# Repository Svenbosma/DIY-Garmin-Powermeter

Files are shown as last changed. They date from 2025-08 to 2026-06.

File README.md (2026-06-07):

# DIY Cycling Power Meter

**What I've made**

A fully working BLE cycling power meter mounted on the left crank of my gravel bike. It broadcasts via Bluetooth using the standard **Cycling Power Profile** so it just shows up as a power meter in Garmin, Wahoo, Zwift, TrainerRoad, or whatever you ride with.

---

## The Story

I am a big nerd and as soon as I got into cycling, I of course wanted more data. The best data for cycling is of course power, so I quickly stumbled down the path of wanting to buy a power meter. Commercial power meters start around €300 and go up fast. I stared at the price tags for a while, then thought: *how hard can it be, it's just a strain gauge readout and some Bluetooth*.

Spoiler: harder than expected. Been working on it (off and on) for a bit less than a year now.

The first version used the **right crank**, which turned out to be a pain. Issues with clearance and wiring routing to the battery which I wanted to fit inside the hollow crank. After some frustration I switched to the **left crank**, which has a larger clearance between rear fork and pedals and makes everything much neater.

### Things I Struggled With

- Getting the HX711 data to be readable
- The Bluetooth Cycling Power Profile spec is... not exactly beginner-friendly documentation
- Getting Garmin to accept and display the zero-offset calibration correctly (there's a whole control-point dance involved)
- **Battery life**, early iterations with 350Ω gauges drew too much current. Switching to **1kΩ Wheatstone bridge sensors** cut standby current dramatically
- Cadence via gyro integration works great but needed careful deadband tuning to avoid phantom revolutions at low speeds
- Making it weatherproof enough for wet rides while still being easy to charge
- Worst of all, testing cadence on my record player. Fine-tuning for weeks because I thought I was off, only to find out my record player was off and the cadence measurement was actually on point. 

The final unit draws **~10mA while riding** and **~0.07mA in standby**. The 300mAh battery lasts a very long time.

---

## The Final Result

| | |
|---|---|
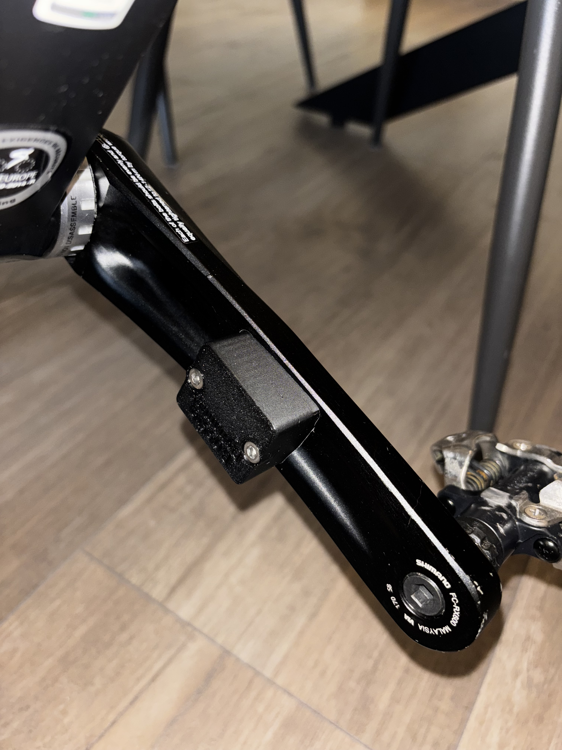
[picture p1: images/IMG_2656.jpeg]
| Mounted on the Shimano left crank |  |
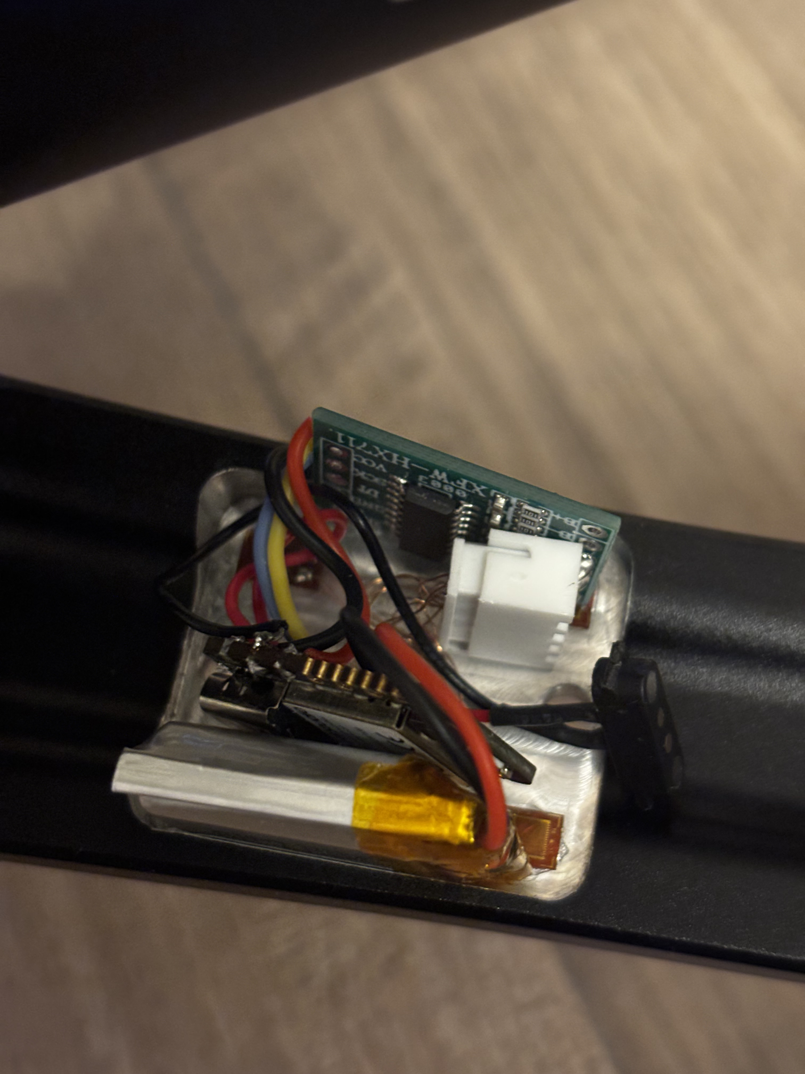
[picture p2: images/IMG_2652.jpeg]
| Electronics on the crank |  |
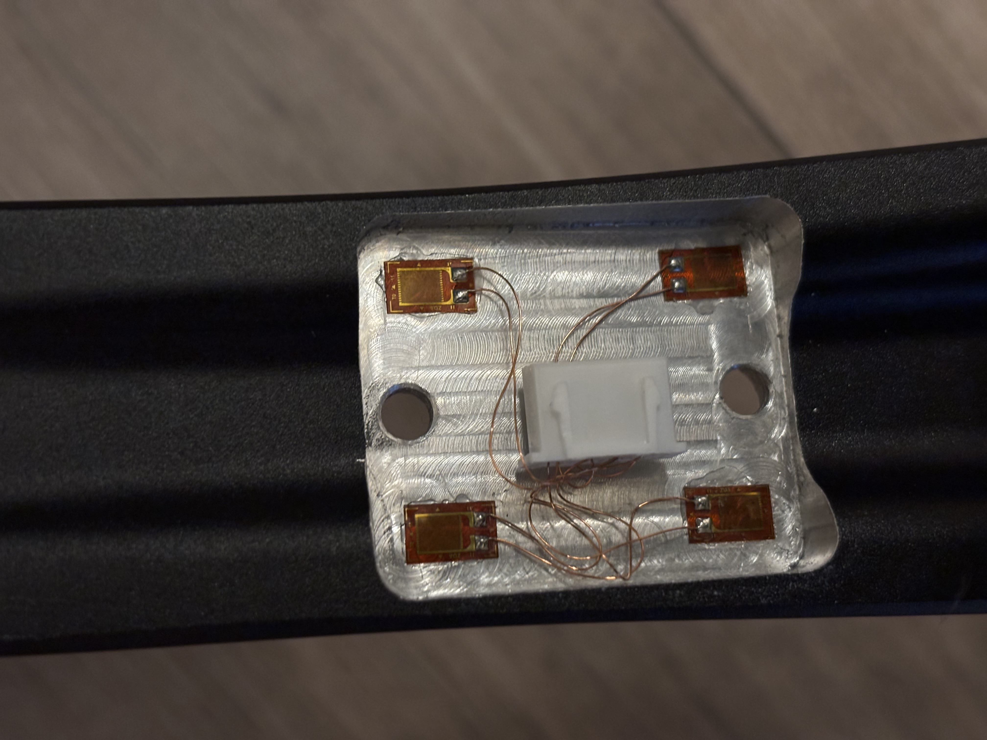
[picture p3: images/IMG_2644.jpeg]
| 4× strain gauges in Wheatstone bridge |  |
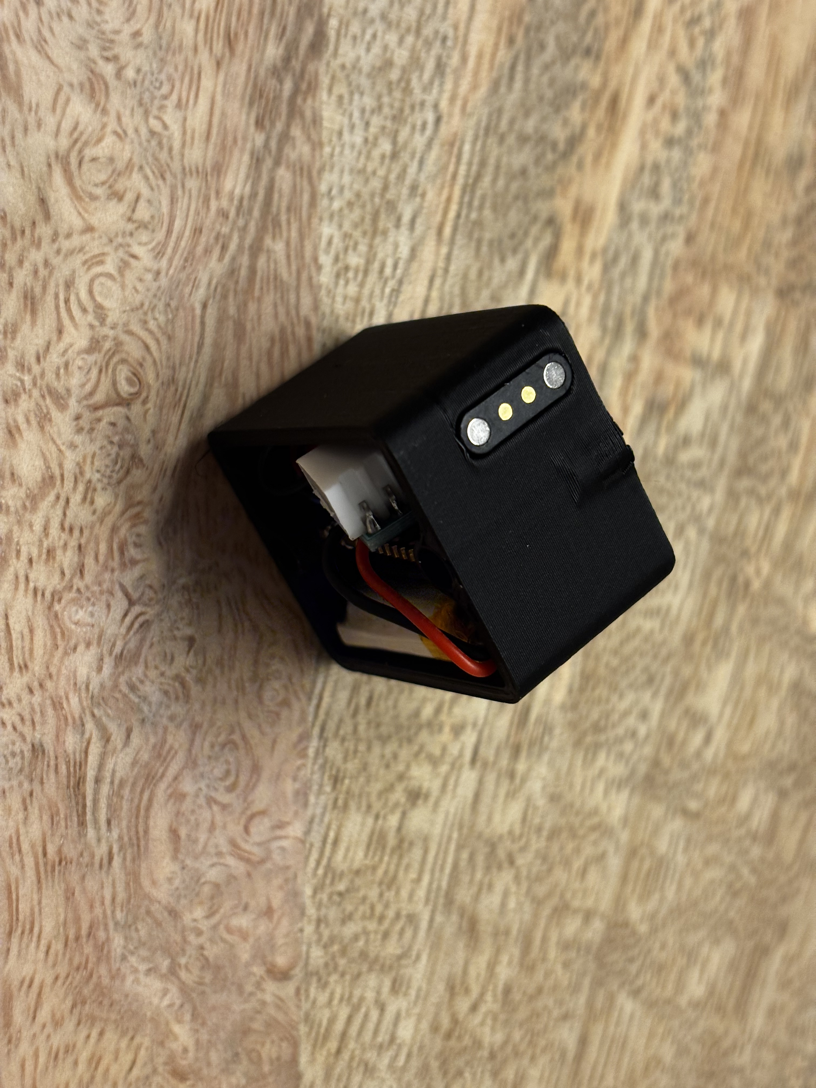
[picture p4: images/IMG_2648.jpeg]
| 3D printed enclosure |  |
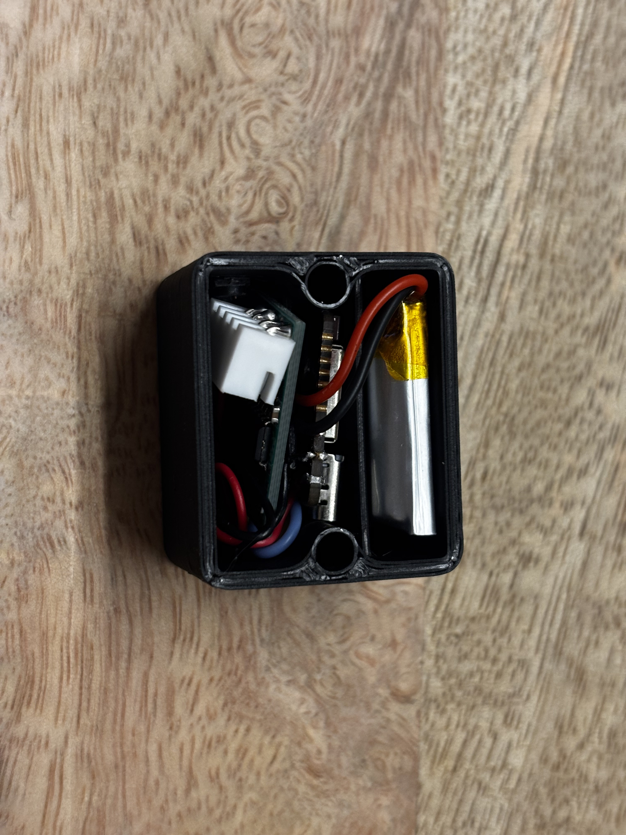
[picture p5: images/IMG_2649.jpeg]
| 3D printed enclosure |  |

Everything: XIAO, HX711, LiPo, and connectors, fits in a small 3D printed box that bolts directly onto the crank arm. I wanted to be able to reach the electronics for testing. But if I were to do it again I would just caulk it on instead of using bolts.

---

## Hardware

| Component | Role | Image |
|---|---|---|
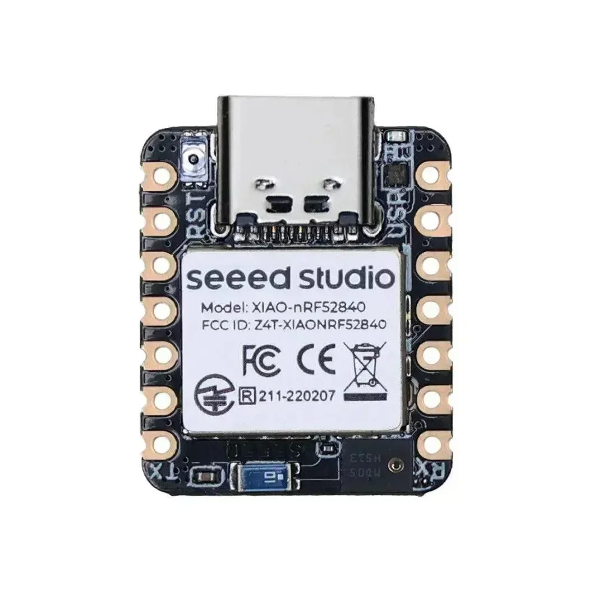
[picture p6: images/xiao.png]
| Seeed XIAO nRF52840 Sense | Microcontroller + BLE + IMU |  |
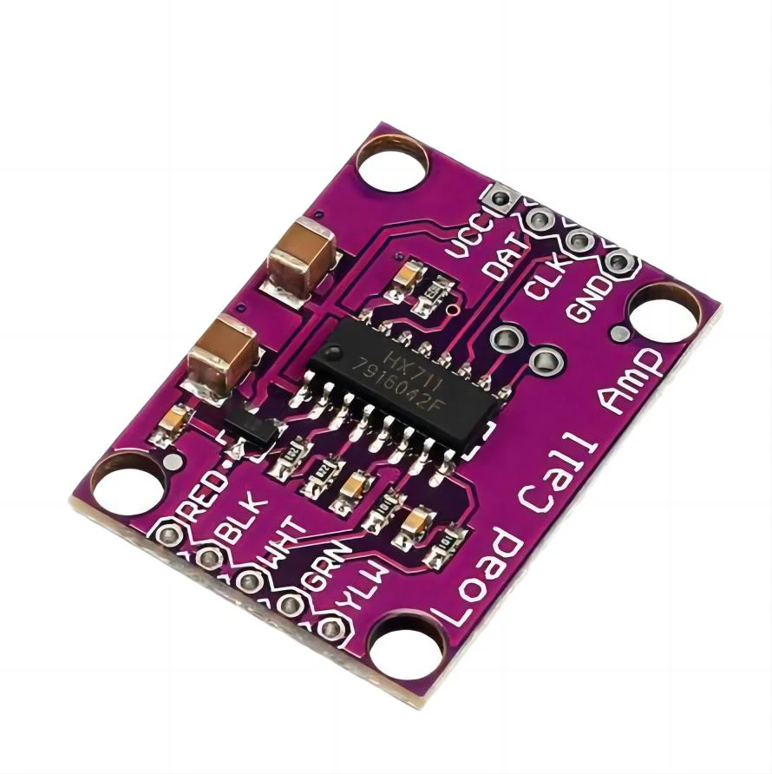
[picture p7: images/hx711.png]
| HX711 | 24-bit strain gauge ADC |  |
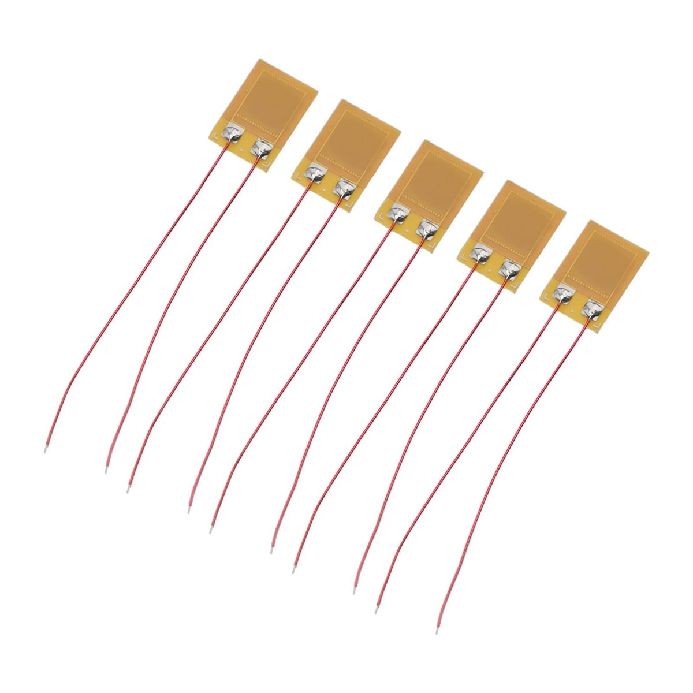
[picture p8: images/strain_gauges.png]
| BF1K-3AA strain gauges (×4) | Measure crank deflection |  |
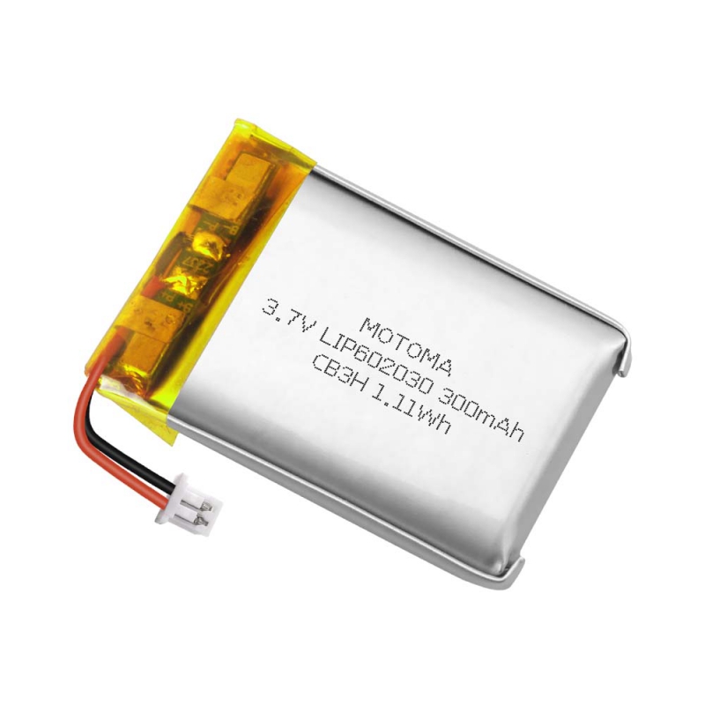
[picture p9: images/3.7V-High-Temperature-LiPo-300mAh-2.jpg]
| 300mAh LiPo | Power |  |
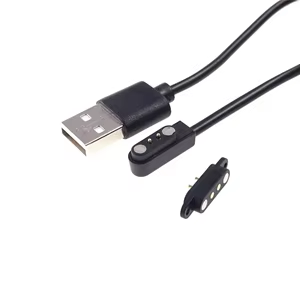
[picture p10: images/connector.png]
| Magnetic charging connector | Weatherproof charging port |  |
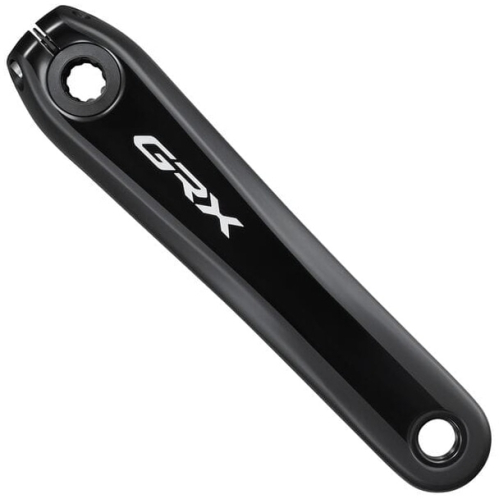
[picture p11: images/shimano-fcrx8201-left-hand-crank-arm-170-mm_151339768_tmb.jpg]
| Shimano left crank arm | I hope this is self explanatory |  |

### Why 1kΩ gauges?

The BF1K-3AA gauges have 1000Ω resistance each. In a full Wheatstone bridge that draws about **3.3mA** from the 3.3V rail, roughly 3× less than the common 350Ω gauges. Longer battery life, approximately the same measurement accuracy. Easy win.

---

## Wiring

```
HX711 DOUT → XIAO D2
HX711 SCK  → XIAO D3
IMU INT1   → XIAO D7   (wake-on-motion)
```

The LSM6DS3 IMU is built into the XIAO, no extra chips needed for cadence. Everything runs from the XIAO's onboard 3.3V regulator.

---

## Software States

### Active — Riding (~10mA)
The HX711 fires an interrupt at ~80Hz. Each sample reads torque and gyro, accumulates values over one full crank revolution, then broadcasts power + cadence via BLE. Battery level is checked every 12 seconds and sent to the head unit.

If you're coasting or going too slow (under 25 RPM), those samples get ignored.

### Deep Sleep — Idle (~0.07mA)
After **60 seconds** of no pedaling the system shuts down completely:
- HX711 powered off (SCK held high)
- MCU enters **System OFF** (nRF52 lowest power state)
- BLE advertising stopped
- Only the IMU accelerometer stays alive, watching for movement

Any movement wakes it back up. Takes about a second to restart and show up in your head unit again.

---

## First Startup & Calibration

Calibration data is stored in internal flash and survives restarts, so you only do this once, or after remounting the gauges.

Connect using any BLE UART app (I recommend the **Adafruit BluefruitConnect** app). The device advertises as **DIY-Powermeter**.

---

### Step 1 — Tare (zero the sensor)

Remove any load from the pedal and make sure nothing is pushing on the crank. Keep it still.

Send:
```
t
```

The device averages 200 HX711 samples, saves the zero offset, and also calibrates the gyro bias (so cadence is accurate from zero). This takes about 3 seconds.

---

### Step 2 — Scale Factor (hang a known weight)

Attach a known mass to the pedal hole (through the spindle thread or a loop of cord). Then send:

```
c          → calibrate with 10kg
m 7.5      → calibrate with 7.5kg (dumbbell, bucket with water, etc.)
```

The 'm' command lets you input any weight. So just weigh anything (preferably above 5kg) and calibrate with this value

The device records the HX711 count shift under that load and computes the counts-per-Newton scale factor. Both tare and scale factor are saved to flash automatically.

**That's it.** From now on the meter works on every boot without re-calibrating. If you ever remount the gauges or feel like the readings drifted, just repeat steps 1 and 2. But remember that Garmin also prompts you to tare every now and then, this should prevent the values from drifting.

---

## BLE UART Commands

| Command | What it does |
|---|---|
| `i` | Print all available commands |
| `t` | Tare + gyro bias calibration (crank unloaded, still) |
| `c` | Calibrate with 10kg reference weight |
| `m <kg>` | Calibrate with custom mass — e.g. `m 12.5` |
| `l` | Toggle debug logging on/off (persisted to flash) |
| `dfu` | Reboot into DFU bootloader for wireless firmware update |

**Logging** spits out cadence, torque, and power after every revolution over UART. Great for debugging, annoying on actual rides. Turn it off once you're happy with it.

### Garmin Zero Offset

Garmin head units have a built-in "Calibrate Power Meter" option in the sensor menu. This sends a BLE Cycling Power Control Point command that triggers an automatic tare, no phone needed while riding. The displayed offset value shows how much drift has accumulated since the last full calibration.

---

## Power Consumption

| State | Current |
|---|---|
| Riding (BLE active, HX711 sampling) | ~10 mA |
| Deep sleep (System OFF, IMU only) | ~0.07 mA |

At 10mA a 300mAh battery gives ~30 hours of riding. In standby it will survive for about 20 weeks realistically. 

---

## Limitations

- **Single-sided** — only left crank measured; power is doubled to estimate total. Assumes left/right balance, which is fine for training.
- **HX711 ADC** — not the most premium ADC out there, but more than sufficient for DIY. Commercial meters use higher-end 24-bit ADCs with better noise isolation.
- **No temperature compensation** — the full Wheatstone bridge cancels most thermal drift, but a quick `t` after warmup never hurts on cold days.

---

## License

Open hardware / open source. Build your own, improve it, make it weirder. Just have fun with it.

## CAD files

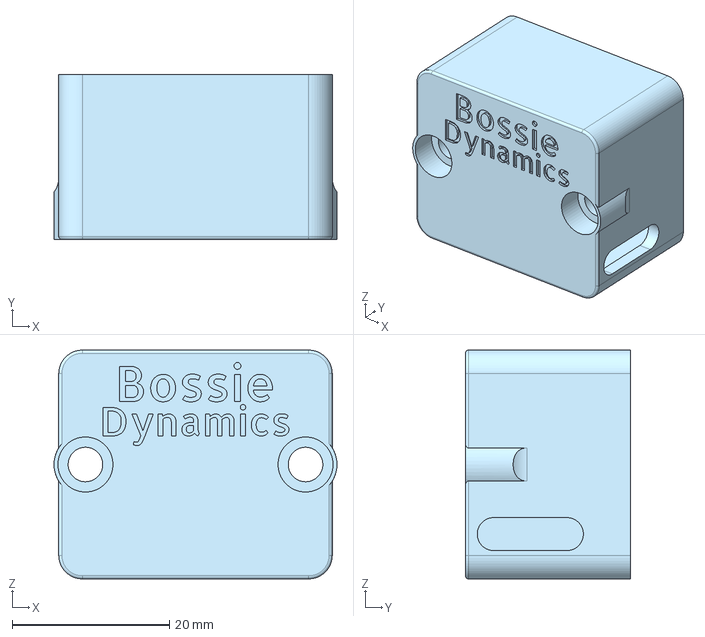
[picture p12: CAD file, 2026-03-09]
Enclosure/PowerMeter.step
36.0 x 21.0 x 29.1 mm

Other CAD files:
Enclosure/PowerMeter.sldprt
Enclosure/PowerMeter.stl

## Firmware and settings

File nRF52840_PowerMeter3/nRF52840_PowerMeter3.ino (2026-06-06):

/*
  DIY Powermeter v3.2
  - HX711 interrupt-driven torque sensor
  - BLE Cycling Power Service + UART calibration/tare
  - Cadence from LSM6DS3 gyro integration
  - Wake-on-motion to exit SYSTEMOFF
 */

#include <bluefruit.h>
#include <Arduino.h>
#include <Wire.h>
#include "HX711.h"
#include <LSM6DS3.h>
#include "nrf_gpio.h"
#include <nrf_sdm.h>
#include <Adafruit_LittleFS.h>
#include <InternalFileSystem.h>
#include <stdint.h>

using namespace Adafruit_LittleFS_Namespace;

#define CAL_FILE   "/calibration.txt"
#define TARE_FILE  "/tare.txt"
#define GYRO_TARE_FILE "/gyro_tare.txt"
#define CRANK_LENGTH_FILE "/crank_length.txt"
#define GARMIN_OFFSET_REF_FILE "/garmin_offset_ref.txt"
#define LOGGING_FILE "/logging.txt"

File calFile(InternalFS);
File tareFile(InternalFS);
File gyroTareFile(InternalFS);

// ---------- config ----------
#define DEFAULT_CRANK_LENGTH_M      0.1725f
#define DEFAULT_CRANK_LENGTH_HALF_MM 345U
#define MIN_POWER_CADENCE_RPM 25.0f
#define MAX_VALID_POWER_W 2000.0f
#define SLEEP_TIMEOUT_MS    60000UL
#define TARE_SAMPLES        200
#define CAL_SAMPLES         200
#define NUM_BATT_SAMPLES 10
#define BATTERY_UPDATE_INTERVAL 12000UL

// ---------- pins ----------
#define HX_DT           2
#define HX_SCK          3
#define MOTION_INT_PIN  PIN_LSM6DS3TR_C_INT1

// Battery state
unsigned long lastBattMs = 0;
uint8_t battPercent = 100;

// IMU
LSM6DS3 myIMU(I2C_MODE, 0x6A);
float gyroBiasY_dps = 0.0f;
float gyroBiasZ_dps = 0.0f;
float lastGyroZ_dps = 0.0f;

// Measurement state
float sumTorqueNm = 0.0f;
int torqueSampleCount = 0;
uint32_t lastRevUs = 0;
uint32_t cumulativeCrankRevs = 0;
uint32_t previousCadenceRevUs = 0;
uint16_t lastCrankEventTime = 0;
uint32_t revolutionTimestampUs = 0;
volatile bool calibrationActive = false;
bool loggingEnabled = true;

// HX711
HX711 scale;
long zeroOffsetCounts = 0;
long garminOffsetReferenceCounts = 0;
bool garminOffsetReferenceValid = false;
float scaleFactor_counts_per_N = NAN;
volatile bool hx711ReadyFlag = false;
uint16_t crankLengthHalfMm = DEFAULT_CRANK_LENGTH_HALF_MM;
float crankLengthM = DEFAULT_CRANK_LENGTH_M;

// Function prototypes
void hx711ISR();
bool detectRevolution(uint32_t sampleMicros, float degZ);
void accumulateTorque(float torqueNm);
bool shouldAccumulateTorqueSample(float torqueNm, float correctedGyroZ_dps);
void configureActiveIMU();
void doTareGyro();
void setupBLE();
void serviceCyclingPowerControlPoint();
void doTare(bool updateGarminReference);
int16_t doGarminOffsetCompensation();
void runCalibration(float knownMassKg);
void sendCyclingPowerMeasurement(int16_t powerWatts,
                                 uint16_t cumulativeCrankRevs,
                                 uint16_t lastCrankEventTime);
void goToSystemOff();
void batteryCheckAndLED();
void CadencePowerCalc(uint32_t revolutionUs);
void loadFlashValues();
void saveCalibration();
void saveTare();
void saveGyroTare();
void saveCrankLength();
void saveGarminOffsetReference();
bool saveLoggingState();
bool setCrankLengthHalfMm(uint16_t halfMm, bool persist);
int16_t getGarminDisplayedOffset();
void ensureGarminOffsetReference();
void uartRXWriteCallback(uint16_t conn_hdl,
                         BLECharacteristic* chr,
                         uint8_t* data,
                         uint16_t len);
void serviceUARTCommands();
void processUARTCommand(String cmd);
void sendCommandInfo();
void setupWakeUpInterrupt();

void uartNotifyChunked(const String &msg);
void logPrint(const String &msg);
void logPrintln(const String &msg);
void logPrint(const char *msg) { logPrint(String(msg)); }
void logPrintln(const char *msg) { logPrintln(String(msg)); }
void logPrint(long v) { logPrint(String(v)); }
void logPrintln(long v) { logPrintln(String(v)); }
void logPrint(unsigned long v) { logPrint(String(v)); }
void logPrintln(unsigned long v) { logPrintln(String(v)); }
void logPrint(int v) { logPrint(String(v)); }
void logPrintln(int v) { logPrintln(String(v)); }
void logPrint(float v, int digits=2) { logPrint(String(v, digits)); }
void logPrintln(float v, int digits=2) { logPrintln(String(v, digits)); }

void cpControlPointWriteCallback(uint16_t conn_hdl,
                                 BLECharacteristic* chr,
                                 uint8_t* data,
                                 uint16_t len);

void setup() {
  logPrintln("DIY Powermeter v3.2 start");
  Wire.begin();

  // Battery measurement and charge-current pin setup for the XIAO board.
  analogReadResolution(12); 
  analogReference(AR_INTERNAL_2_4);
  pinMode(PIN_CHARGING_CURRENT, OUTPUT);
  digitalWrite(PIN_CHARGING_CURRENT, LOW);
  pinMode(VBAT_ENABLE, OUTPUT); 
  digitalWrite(VBAT_ENABLE, LOW);
  pinMode(PIN_VBAT, INPUT);

  // HX711 runs from the data-ready interrupt; keep SCK low when active.
  pinMode(HX_SCK, OUTPUT); digitalWrite(HX_SCK, LOW);
  pinMode(HX_DT, INPUT_PULLUP);
  scale.begin(HX_DT, HX_SCK);
  delay(75);
  attachInterrupt(digitalPinToInterrupt(HX_DT), hx711ISR, FALLING);

  delay(1000);
  logPrintln("Starting IMU...");
  configureActiveIMU();
  int imuStatus = myIMU.begin();
  logPrint("IMU begin result = ");
  logPrintln(String(imuStatus));

  if (imuStatus != 0) {
    logPrintln("IMU init failed!");
    while (1);
  }

  // Load persisted tare/calibration before starting BLE service.
  loadFlashValues();
  setupBLE();
  lastRevUs = micros();
  logPrintln("Ready. Commands via UART: 'i'=info, 'l'=logging, 'c'=calib, 't'=tare, 'm <kg>'=custom calib.");
}

void loop() {
  serviceUARTCommands();
  serviceCyclingPowerControlPoint();

  // Each HX711 sample updates torque and provides the pacing for the main loop.
  if (hx711ReadyFlag) {
    hx711ReadyFlag = false;
    long raw = scale.read();
    uint32_t sampleMicros = micros();
    float rawGyroZ_dps = myIMU.readFloatGyroZ();
    float correctedGyroZ_dps = rawGyroZ_dps - gyroBiasZ_dps;
    long net = raw - zeroOffsetCounts;

    if (isfinite(scaleFactor_counts_per_N) && fabs(scaleFactor_counts_per_N) > 1e-6f) {
      float forceN = (float)net / scaleFactor_counts_per_N;
      float torqueNm = forceN * crankLengthM;
      if (shouldAccumulateTorqueSample(torqueNm, correctedGyroZ_dps)) {
        accumulateTorque(torqueNm);
      }
    }
    lastGyroZ_dps = rawGyroZ_dps;
    float degZ = rawGyroZ_dps;
    if (detectRevolution(sampleMicros, degZ)) {
      CadencePowerCalc(revolutionTimestampUs);
    }
  }

  if ((micros() - lastRevUs) > (SLEEP_TIMEOUT_MS * 1000UL) && !calibrationActive) {
    logPrintln("No pedaling -> deep sleep");
    goToSystemOff();
  }

  batteryCheckAndLED();
  sd_app_evt_wait();
}

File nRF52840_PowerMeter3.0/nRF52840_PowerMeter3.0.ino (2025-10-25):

/*
  DIY Powermeter v3.2
  - HX711 interrupt-driven torque sensor
  - BLE Cycling Power Service + UART calibration/tare
  - Cadence from BMI270/LSM6DS3: accel X zero-cross + gyro X sign
  - Wake-on-motion to exit SYSTEMOFF (using double tap)
*/

#include <bluefruit.h>
#include <Adafruit_TinyUSB.h>
#include <Arduino.h>
#include <Wire.h>
#include "HX711.h"
#include "LSM6DS3.h"
#include "nrf_gpio.h"

// ---------- config ----------
#define CRANK_LENGTH_M      0.1725f
#define ACCEL_THRESHOLD_G   0.05f
#define SLEEP_TIMEOUT_MS    60000UL
#define TARE_SAMPLES        200
#define CAL_SAMPLES         200
#define GYRO_FORWARD_THRESHOLD 0.0f
#define LOW_BATT_THRESHOLD 20
#define NUM_BATT_SAMPLES 10
#define BATTERY_UPDATE_INTERVAL 6000UL
#define BLINK_INTERVAL 300
#define NUM_BLINKS 3

// ---------- pins ----------
#define HX_DT           2
#define HX_SCK          3
#define MOTION_INT_PIN  PIN_LSM6DS3TR_C_INT1

// Battery
unsigned long lastBattMs = 0;
unsigned long lastBlinkMs = 0;
uint8_t battPercent = 100;
uint8_t blinkCount = 0;
bool ledState = false;

// IMU
LSM6DS3 myIMU(I2C_MODE, 0x6A);

// Torque + IMU accumulators
float sumTorqueNm = 0.0f;
int torqueSampleCount = 0;
int imuSampleCount = 0;
float sumGyroX = 0.0f, sumAccelX = 0.0f;
unsigned long lastRevMs = 0;
uint32_t cumulativeCrankRevs = 0;
uint16_t lastCrankEventTime = 0;
bool prevAccelPositive = false;

// HX711
HX711 scale;
long zeroOffsetCounts = 0;
float scaleFactor_counts_per_N = NAN;
volatile bool hx711ReadyFlag = false;

// prototypes
void hx711ISR();
void setupBLE();
void doTare();
void runCalibration(float knownMassKg);
void sendCyclingPowerMeasurement(int16_t powerWatts);
void handleUART();
void goToSystemOff();
void batteryCheckAndLED();
void CadencePowerCalc();
float ReadGxFIFO();

void logPrint(const String &msg);
void logPrintln(const String &msg);
void logPrint(const char *msg) { logPrint(String(msg)); }
void logPrintln(const char *msg) { logPrintln(String(msg)); }
void logPrint(long v) { logPrint(String(v)); }
void logPrintln(long v) { logPrintln(String(v)); }
void logPrint(unsigned long v) { logPrint(String(v)); }
void logPrintln(unsigned long v) { logPrintln(String(v)); }
void logPrint(int v) { logPrint(String(v)); }
void logPrintln(int v) { logPrintln(String(v)); }
void logPrint(float v, int digits=2) { logPrint(String(v, digits)); }
void logPrintln(float v, int digits=2) { logPrintln(String(v, digits)); }

void setup() {
  // -- Peripheral and pin setup --
  Serial.begin(115200);
  unsigned long start = millis();
  while (!Serial && (millis() - start < 2000)) {}
  logPrintln("DIY Powermeter v3.1 start");
  Wire.begin();
  analogReadResolution(12); 

  // ---- HX711 setup ----
  nrf_gpio_cfg_output(13);   // P0.13
  nrf_gpio_pin_clear(13);    // LOW = 100 mA
  pinMode(HX_SCK, OUTPUT); digitalWrite(HX_SCK, LOW);
  pinMode(HX_DT, INPUT_PULLUP);
  scale.begin(HX_DT, HX_SCK);
  delay(75);
  attachInterrupt(digitalPinToInterrupt(HX_DT), hx711ISR, FALLING);

/*  // ---- Imu setup ----
  myIMU.settings.gyroEnabled = 1;
  myIMU.settings.gyroRange = 2000;       // safe for up to ~1200 °/s
  myIMU.settings.gyroSampleRate = 833;   // Hz
  myIMU.settings.gyroBandWidth = 100;    // Hz low-pass filter
  myIMU.settings.gyroFifoEnabled = 1;
  myIMU.settings.gyroFifoDecimation = 1;
  // Disable accel & temp & timestamp
  myIMU.settings.accelEnabled = 0;
  myIMU.settings.tempEnabled  = 0;
  myIMU.settings.timestampEnabled = 0;
  myIMU.settings.timestampFifoEnabled = 0;
  //Non-basic mode settings
  myIMU.settings.commMode = 1;
  // FIFO settings
  myIMU.settings.fifoThreshold = 0;     // not   used
  myIMU.settings.fifoSampleRate = 800;  // match gyro ODR
  myIMU.settings.fifoModeWord = 6;      // continuous mode*/
  if (myIMU.begin() != 0) {
    logPrintln("IMU init failed!");
    while(1);
  }
  //myIMU.fifoBegin();
  //myIMU.fifoClear();

  // ---- Startup routine ----
  setupBLE();
  doTare();
  lastRevMs = millis();
  logPrintln("Ready. Commands via UART: 'c'=calib, 't'=tare, 'm <kg>'=custom calib.");
}

void loop() {
  float hz = getAverageHz();
  // Only print once per second when updated
  static float lastHz = 0.0;
  if (hz != lastHz) {
    logPrint("Average Hz: ");
    logPrintln(hz, 2);  // Two decimal precision
    lastHz = hz;
  }

  handleUART();  // BLE UART handling

  // HX711
  if (hx711ReadyFlag) {
    hx711ReadyFlag = false;
    long raw = scale.read();
    long net = raw - zeroOffsetCounts;

    if (isfinite(scaleFactor_counts_per_N) && fabs(scaleFactor_counts_per_N) > 1e-6f) {
      float forceN = (float)net / scaleFactor_counts_per_N;
      float torqueNm = forceN * CRANK_LENGTH_M;
      accumulateTorque(torqueNm);
    }
  }

  // IMU
  //  gx = ReadGxFIFO();
  //logPrint(gx);
  //logPrint(" Sampled vs normal ");
  float gx = myIMU.readFloatGyroX();
  //logPrintln(gx);
  accumulateIMU(gx);

  if (detectRevolution(gx)) {
    CadencePowerCalc();
  }

  if ((millis() - lastRevMs) > SLEEP_TIMEOUT_MS) {
    logPrintln("No pedaling -> deep sleep");
    goToSystemOff();
  }

  batteryCheckAndLED();
}

// --- Global variables ---
unsigned long lastTime = 0;
unsigned long loopCount = 0;
float avgHz = 0.0;

float getAverageHz() {
  loopCount++;  // Count each loop iteration

  unsigned long now = millis();
  unsigned long elapsed = now - lastTime;

  if (elapsed >= 1000) {  // Every 1 second
    avgHz = (float)loopCount * 1000.0 / (float)elapsed;  // Loops per second
    loopCount = 0;
    lastTime = now;
  }

  return avgHz;
}

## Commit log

2025-08-29 Test file for power meter
    In future, combine with low power test
2025-09-01 Added sleep inbetween the hx711 data ready cycles
    Now uses a interrupt from HX711 to go out of sleep mode. configure HX711 to 80Hz for correct usage.
    [nRF52840_PowerMeter3.0.ino]
2025-09-14 Bugfixes and OTA support + BLE phone control
    [nRF52840_PowerMeter3.0.ino]
2025-10-25 Test for reading the fifo of IMU
2026-02-07 Huge Update (finally)
    Fifo reading the LSM6DS3 instead of polling.
    Lower power consumption, can now run of a 300mAh battery.
2026-03-09 Add 3D files
    [PowerMeter.sldprt, PowerMeter.step, PowerMeter.stl]
2026-03-14 Code cleanup
    Cleaner code and added 2x multiplier to the power to compensate for left crank only measurement
2026-04-04 Working version
    Only change left:
    Disable UART?
    Add averaging of power
    Make negative power impossible
